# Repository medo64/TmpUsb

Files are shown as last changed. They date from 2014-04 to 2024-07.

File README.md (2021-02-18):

# TmpUsb

TmpUsb is presented to a computer as an USB disk drive 11 KB in size (7-8 KB
usable). This drive can be then used to store any data (providing that size is
not the issue) but primary idea is to use it for the encryption keys. Once all
data has been copied to it, user would perform "arming" thus enabling
self-erase after approximately 3 seconds of being unplugged.

Basic use case for such behavior would be a BitLocker key storage. Having
encrypted server brings a lot of security benefits but with a cost of
re-entering keys on every restart. BitLocker can work around that by allowing
you to store keys on USB in order to decrypt content automatically.
Unfortunately this means that, if your server is stolen, you also give your
encryption key with it thus nullifying encryption.

By using TmpUsb your encryption keys will be deleted rendering data on stolen
server completely unusable. While this won't bring your server back, at least
data won't be readable any more.

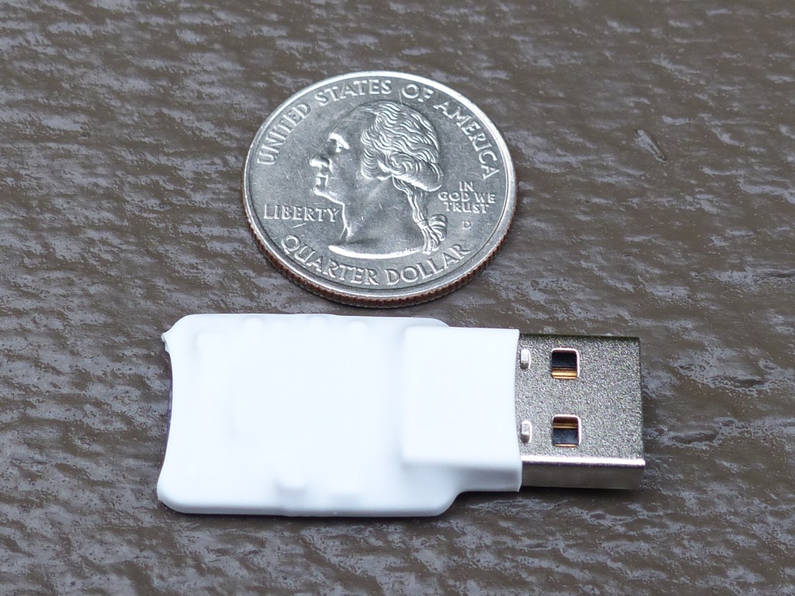
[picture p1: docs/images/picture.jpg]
TmpUsb


## How It Works

When you plug TmpUsb in for the first time, it will start in "Not Armed" mode,
as visible from drive's label. Visually you would recognize this mode by the
fact that LED is on. At that time you can freely use it as you would any
standard USB drive. At this time you would copy your encryption keys to it and
change its label to "Arm" and unplug it.

On next plug-in (might be on another computer) LED will turn off and drive will
be considered armed. In this state drive will still behave as a standard USB
drive but only while it has power. If there is a power loss longer than
approximately three seconds (configurable, to allow for computer reset) drive
will self-erase and return to an empty state.

## LED

There is a single LED on a drive. If it is on, drive hasn't been armed and it
is safe to unplug it without going into risk of losing data to self-erase. Once
drive is armed, LED will turn off.

Upon self-erase, device will quickly blink three times. If self erasure was due
to validation error (i.e. drive content was corrupted) it will blink five
times.

## Commands

All commands are entered by changing drive label. Casing is not important.

### Arm

Gives command to TmpUsb to be "armed" on next plugin. This fits scenario where
user prepares encryption keys on one computer, arms TmpUsb and then plugs it in
on another computer. Only once TmpUsb has been plugged in for a second time, it
is considered armed and any further label changes won't change that status. In
this mode TmpUsb will tolerate short power loss (approximate three seconds) but
anything longer will trigger self-erase.

### ArmMax

As with Arm command, this will cause TmpUsb to be armed on next plugin.
However, unlike with Arm command, any power failure will trigger self-erasure
regardless of power-loss duration. On most computers this means that
self-erasure will be also triggered by a simple reset.

### Armed

Immediately "arms" TmpUsb without need to wait until next plugin. This is
useful in case where preparation of encryption keys is done on same computer
where those keys are to be used. It is just a shortcut that skips need for
unplug-plug that Arm command needs. Once armed, LED will be turned off and
status will remain armed even if drive label gets further changes.

### Calibrate

If standard power-loss buffer duration (approximately three seconds) is not
satisfactory, user can change drive label to `Calibrate` and unplug the drive.
Once drive is plugged back in, it will determine duration it was plugged out
for and use that as a new default. Notice that drive will be erased and its
label will say what is raw ADC value for given time. Do try to avoid values
less than 3. Due to nature of time keeping via the capacitor, values are really
rough and they are unusable beyond 10 seconds. Value determined by this
procedure will be used until either ArmMax or Reset are given. At that time
TmpUsb will revert to default three seconds.

### Reset

On next plug-in TmpUsb will perform self-erasure together with reset of all
settings.

## Security Risks

As expected, there are some security risks involved.

Major one is connected with fact that erasure of data, due to TmpUsb having no
battery, is possible only on next plug-in. If attacker is fast enough, he can
plug TmpUsb in another computer without triggering erasure. Mitigation strategy
for this attack is using `ArmMax` command in order to trigger erasure as soon
as power is lost.

Similarly, attacker can charge capacitor without actually turning TmpUsb on. On
next plug-in TmpUsb will think that less time passed than it actually has.
Mitigation strategy is also using `ArmMax` command.

Even using `ArmMax` you are not safe if attacker is technically savvy and has
access to TmpUsb that is currently working. It can put another power source in
parallel to USB and thus TmpUsb won't be aware at any time that the power was
lost.

Internal key storage is encrypted using the security feature of microcontroller
itself. In ideal world this would mean that, even if attacker has direct access
to chip, nobody would be able to read data without running it first. Of
course, this is intended to stop normal attackers only. Somebody with unlimited
resources (e.g. NSA) will not be deterred by this.

Regardless of these attacks, TmpUsb will probably protect you from 99.9%
attackers, especially if they are not aware its presence. It is not be-all and
end-all device but it surely beats keeping keys on a normal USB drive.

## Known Issues

Device has no battery, time is kept only by monitoring voltage decay on a big
capacitor. Major downfall is the fact that such timing is imprecise and doesn't
allow for a big time spans. In practice TmpUsb can deal with up to 10 seconds
of delay.

Since most operating systems cannot really format such a small drive and such
attempt might possibly damage logical structure, decision has been made to
check MBR and boot sector (including partition table) areas on every boot.
Effect of this verification is that any change to verified areas is not
possible and drive will self-erase if such change is noted.

Chip used for TmpUsb has flash specified for at least 10000 write cycles. Since
there is no block remapping as it is custom on the modern flash drives, this
roughly means that you can safely write to this drive approximately 5000 times
(it does suffer from high write amplification). While it will probably handle a
bit more, this is definitely not the device when constant writing is expected.

Total size of this drive is 11 KB. However, this is not a size user will have
available. Six sectors (3 KB) are immediately taken by mandatory MBR and boot
sector, followed by FAT and a root directory entries. OS only gets to see 8 KB.
Once drive is plugged-in, some Windows versions will add its System Volume
Information folder on each drive it sees and that means that it gets hit with
additional 1 KB penalty and at least four directory entries are gone. Under
Windows available size is thus 7-8 KB (depending on version) while we get 8 KB
under Linux.

---

*You can check my blog and other projects at [www.medo64.com](https://www.medo64.com/).*

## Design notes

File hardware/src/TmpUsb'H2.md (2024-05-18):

## TmpUsb: USB H2 plug

| | |
|---|---|
| Size | 26.0 x 17.0 mm ~ 0.7 sqin |
| VID  | 0x04D8 |
| PID  | 0xF777 |

### Parts

|  # | Part name | RefDes  | DigiKey |
|---:|---|---|---|
|  2 | C 100nF /10V X7R (0805) | C1 C2 | 399-1167-1-ND |
|  2 | C 1uF /10V X5R (0805) | C3 C4 | 1276-6471-1-ND |
|  2 | C 10uF /10V X5R (0805) | C5 C6 | 478-5167-6-ND |
|  2 | D Schottky 30V 800mA (SOD323) | D1-D2 | CUS08F30H3FCT-ND |
|  1 | DS LED (0805) | DS1 | 475-1415-1-ND |
|  1 | L Ferrite 40Ohm (0805) | L1 | 445-2201-1-ND |
|  1 | J USB 2x5 plug, horizontal | J1 | A106395-ND |
|  1 | J AMP 292133-3 (3w) | J2 | A100945-ND |
|  2 | R 1K 0.125W (0805) | R1 R2 | RMCF0805FT1K00CT-ND |
|  1 | R 10K 0.125W (0805) | R3 | RMCF0805JT10K0CT-ND |
|  1 | R 100K 0.125W (0805) | R4 | RMCF0805JT100KCT-ND |
|  1 | U PIC18F26J50-I/SS (SSOP-28) | U1 | PIC18F26J50-I/SS-ND |
|  1 | VR MCP1700 (SOT-23) | VR1 | MCP1700T3302ETTCT-ND |

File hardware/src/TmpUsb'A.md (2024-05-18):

## TmpUsb: USB A plug

| | |
|---|---|
| Size | 26.0 x 17.0 mm ~ 0.7 sqin |
| VID  | 0x04D8 |
| PID  | 0xF777 |

### Parts

|  # | Part name | RefDes  | DigiKey | Newark  |
|---:|---|---|---|---|
|  2 | C 100nF /10V X7R (0805) | C1 C2 | 399-1167-1-ND | 68R4903 |
|  2 | C 1uF /10V X5R (0805) | C3 C4 | 1276-6471-1-ND | 97K0638 |
|  2 | C 10uF /10V X5R (0805) | C5 C6 | 478-5167-6-ND | 13T1208 |
|  1 | DS LED (0805) | DS1 | 475-1415-1-ND | 34C8663 |
|  1 | L Ferrite 40Ohm (0805) | L1 | 445-2201-1-ND | 89R3121 |
|  1 | J USB A, plug, horizontal | J1 | WM3983CT-ND | 01J8375 |
|  2 | R 1K 0.125W (0805) | R1 R2 | RMCF0805FT1K00CT-ND | 01P2109 |
|  1 | R 10K 0.125W (0805) | R3 | RMCF0805JT10K0CT-ND | 05M4535 |
|  1 | R 100K 0.125W (0805) | R4 | RMCF0805JT100KCT-ND | 68R0231 |
|  1 | U PIC18F26J50-I/SS (SSOP-28) | U1 | PIC18F26J50-I/SS-ND | 98M1806 |
|  1 | VR MCP1700 (SOT-23) | VR1 | MCP1700T3302ETTCT-ND | 88H9817 |

1/2" heat-shrink tubing, 30mm

### Suggested Soldering order

Here is the suggested order for easy hand soldering.

|  # | Part name | RefDes  |
|---:|---|---|
|  1 | U PIC18F26J50-I/SS (SSOP-28) | U1 |
|  1 | VR MCP1700 (SOT-23) | VR1 |
|  2 | C 100nF /10V X7R (0805) | C1 C2 |
|  2 | C 1uF /10V X5R (0805) | C3 C4 |
|  2 | C 10uF /10V X5R (0805) | C5 C6 |
|  1 | L Ferrite 40Ohm (0805) | L1 |
|  1 | DS LED (0805) | DS1 |
|  1 | R 10K 0.125W (0805) | R3 |
|  2 | R 1K 0.125W (0805) | R1 R2 |
|  1 | R 100K 0.125W (0805) | R4 |
|  1 | P USB A, plug, horizontal | P1 |

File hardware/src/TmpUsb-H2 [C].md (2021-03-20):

## TmpUsb: USB 2.0 motherboard header

This variant is intended for direct plug into the motherboard's 2.0 header.

| | |
|---|---|
| Size | 21.0 x 17.0 mm ~ 0.6 sqin |
| VID  | 0x04D8 |
| PID  | 0xF777 |

### Parts

|  # | Part name | RefDes  | DigiKey |
|---:|---|---|---|
|  2 | C 100nF /10V X7R (0805) | C1 C2 | 311-1142-1-ND |
|  2 | C 1uF /10V X5R (0805) | C3 C4 | 1276-6471-1-ND |
|  2 | C 10uF /10V X5R (0805) | C5 C6 | 478-5167-6-ND |
|  1 | DS LED (0805) | DS1 | 475-1415-1-ND |
|  1 | L Ferrite 40Ohm (0805) | L1 | 445-2201-1-ND |
|  1 | P USB2 Header F (2x5w) | P1 | A106395-ND † |
|  2 | R 1K 0.125W (0805) | R1 R2 | RMCF0805FT1K00CT-ND  |
|  1 | R 10K 0.125W (0805) | R3 | RMCF0805JT10K0CT-ND  |
|  1 | R 100K 0.125W (0805) | R4 | RMCF0805JT100KCT-ND  |
|  1 | U PIC18F26J50-I/SS (SSOP-28) | U1 | PIC18F26J50-I/SS-ND  |
|  1 | VR MCP1700 (SOT-23) | VR1 | MCP1700T3302ETTCT-ND |

† This connector is not an excellent match but the best I could find on
  DigiKey.

### Suggested Soldering order

Here is the suggested order for easy hand soldering.

|  # | Part name | RefDes  |
|---:|---|---|
|  1 | U PIC18F26J50-I/SS (SSOP-28) | U1 |
|  1 | VR MCP1700 (SOT-23) | VR1 |
|  2 | R 1K 0.125W (0805) | R1 R2 |
|  1 | R 10K 0.125W (0805) | R3 |
|  1 | R 100K 0.125W (0805) | R4 |
|  2 | C 10uF /10V X5R (0805) | C5 C6 |
|  2 | C 1uF /10V X5R (0805) | C3 C4 |
|  2 | C 100nF /10V X7R (0805) | C1 C2 |
|  1 | L Ferrite 40Ohm (0805) | L1 |
|  1 | DS LED (0805) | DS1 |
|  1 | P USB2 Header F (2x5w) | P1 |

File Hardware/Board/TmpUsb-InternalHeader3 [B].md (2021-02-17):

### TmpUsb ###

This variant is intended for direct plug into the motherboard's 3.0 header.

| | |
|---|---|
| Size | 24.0 x 22.0 mm ~ 0.8 sqin |
| VID  | 0x04D8 |
| PID  | 0xF777 |

#### Parts ####

|  # | Part name | RefDes  | DigiKey |
|---:|---|---|---|
|  2 | C 100nF /10V X7R (0603) | C1 C2 | 1276-1934-1-ND |
|  2 | C 1uF /10V X5R (0605) | C3 C4 | 1276-6524-1-ND |
|  2 | C 10uF /10V X5R (0805) | C5 C6 | 1276-1119-1-ND |
|  1 | DS LED (0805) | DS1 | 160-1468-1-ND |
|  1 | J USB A 3.0, receptacle, horizontal  | J1 | 609-4662-ND |
|  1 | L Ferrite 30Ohm (0603) | L1 | 490-1035-1-ND |
|  1 | P USB header, r/a plug | P1 | SQW-110-01-L-D-020 † |
|  2 | R 1K 0.1W (0603) | R1 R2 | RMCF0603FT1K00CT-ND  |
|  1 | R 10K 0.1W (0603) | R3 | RMCF0603FT10K0CT-ND  |
|  1 | R 100K 0.1W (0603) | R4 | RMCF0603FT100KCT-ND  |
|  1 | U PIC18F26J50-I/SS (SSOP-28) | U1 | PIC18F26J50-I/SS-ND  |
|  1 | VR MCP1700 (SOT-23) | VR1 | MCP1700T3302ETTCT-ND |

† This connector is not an excellent match but the best I could find on
  DigiKey. It seems that blue USB connector is only available on Chinese
  sites.

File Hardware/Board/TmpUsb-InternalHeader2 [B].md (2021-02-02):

### TmpUsb ###

This variant is intended for direct plug into the motherboard's 2.0 header.

| | |
|---|---|
| Size | 28.0 x 17.5 mm ~ 0.8 sqin |
| VID  | 0x04D8 |
| PID  | 0xF777 |

#### Parts ####

|  # | Part name | RefDes  | DigiKey | Newark  |
|---:|---|---|---|---|
|  2 | C 100nF /10V X7R (0805) | C1 C2 | 311-1142-1-ND | 68R4903 |
|  2 | C 1uF /10V X5R (0805) | C3 C4 | 1276-6471-1-ND | 97K0638 |
|  2 | C 10uF /10V X5R (0805) | C5 C6 | 478-5167-6-ND | 13T1208 |
|  1 | DS LED (0805) | DS1 | 475-1415-1-ND | 34C8663 |
|  1 | J USB A, receptable, horizontal  | J1 | ED2989-ND | 46P5302 |
|  1 | L Ferrite 40Ohm (0805) | L1 | 445-2201-1-ND | 89R3121 |
|  1 | P USB header, r/a plug | P1 | S5558-ND | 15P2884 |
|  2 | R 1K 0.125W (0805) | R1 R2 | RMCF0805FT1K00CT-ND | 01P2109 |
|  1 | R 10K 0.125W (0805) | R3 | RMCF0805JT10K0CT-ND | 05M4535 |
|  1 | R 100K 0.125W (0805) | R4 | RMCF0805JT100KCT-ND | 68R0231 |
|  1 | U PIC18F26J50-I/SS (SSOP-28) | U1 | PIC18F26J50-I/SS-ND | 98M1806 |
|  1 | VR MCP1700 (SOT-23) | VR1 | MCP1700T3302ETTCT-ND | 88H9817 |

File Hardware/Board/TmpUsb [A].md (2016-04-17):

### TmpUsb ###

| | |
|---|---|
| Size | 22.5 x 17.0 mm ~ 0.6 sqin |
| VID  | 0x04D8 |
| PID  | 0xF777 |

#### Parts ####

|  # | Part name | RefDes  | DigiKey | Newark  |
|---:|---|---|---|---|
|  2 | C 100nF /16V X7R (0805) | C1 C2 | 399-1170-1-ND | 68R4903 |
|  2 | C 1uF /16V X5R (0805) | C3 C4 | 490-1691-1-ND | 97K0638 |
|  2 | C 10uF /16V X5R (0805) | C5 C6 | 399-8013-1-ND | 13T1208 |
|  1 | DS LED (0805) | DS1 | 475-1415-1-ND | 34C8663 |
|  1 | L Ferrite 40Ohm (0805) | L1 | 445-2201-1-ND | 89R3121 |
|  1 | P USB A, plug, horizontal | P1 | WM3983CT-ND | 01J8375 |
|  2 | R 1K 0.125W (0805) | R1 R2 | RMCF0805FT1K00CT-ND | 01P2109 |
|  1 | R 10K 0.125W (0805) | R3 | RMCF0805JT10K0CT-ND | 05M4535 |
|  1 | R 100K 0.125W (0805) | R4 | RMCF0805JT100KCT-ND | 68R0231 |
|  1 | U PIC18F26J50-I/SS (SSOP-28) | U1 | PIC18F26J50-I/SS-ND | 98M1806 |
|  1 | VR MCP1700 (SOT-23) | VR1 | MCP1700T3302ETTCT-ND | 88H9817 |

1/2" heat-shrink tubing, 30mm

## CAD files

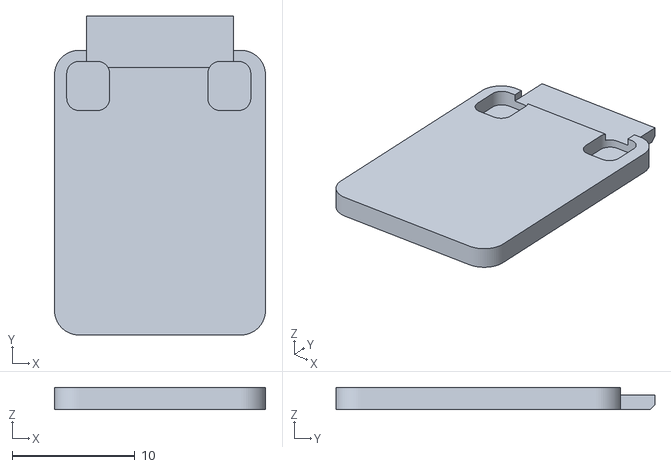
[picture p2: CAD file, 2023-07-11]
hardware/src/case/TmpUsb'A Case Bottom.stl
17.2 x 26.0 x 1.80

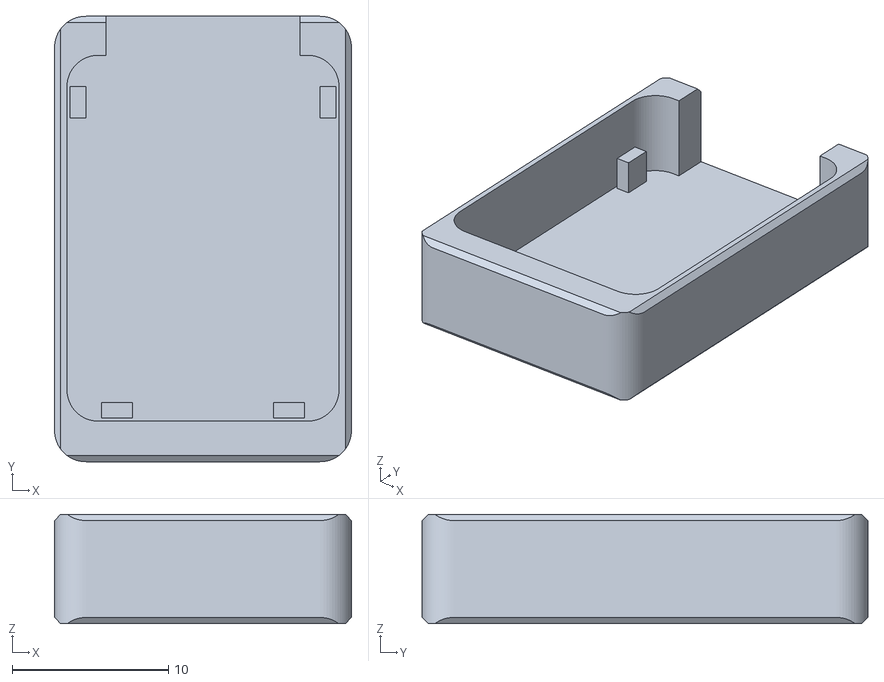
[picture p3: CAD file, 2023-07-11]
hardware/src/case/TmpUsb'A Case Top.stl
19.0 x 28.5 x 7.00

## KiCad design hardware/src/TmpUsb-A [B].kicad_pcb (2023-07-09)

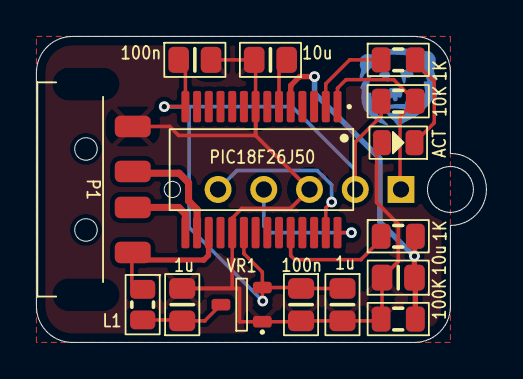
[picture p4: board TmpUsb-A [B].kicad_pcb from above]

Board: 2 copper layers, 25.0 x 17.0 mm, 16 parts (1 on the bottom side), 12 nets.

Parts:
C1, C2: 100n; C (0805)
C3, C4: 1u; C (0805)
C5, C6: 10u; C (0805)
DS1: ACT; DS (0805)
L1: 40R; L Ferrite (0805)
P1: 48037-2200; P USB 2.0 (4w)
R1, R2: 1K; R (0805)
R3: 10K; R (0805)
R4: 100K; R (0805)
U1: PIC18F26J50; U Micro PIC18F26J50 (SSOP-28)
VR1: MCP1700; VR LDO MCP1700 (SOT23-3)
Z?: Medo64; Z Icon [Medo64]

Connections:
+3.3V: C1.1, C2.1, C4.1, R3.1, U1.14, U1.20, VR1.2
+5V: C3.1, L1.2, VR1.3
CAP: C6.1, R2.2, R4.1, U1.5
CAP_POWER: R2.1, U1.24
GND: C1.2, C2.2, C3.2, C4.2, C5.2, C6.2, DS1.2, P1.4, R4.2, U1.8, U1.19, VR1.1
ICSP_VPP: R3.2, U1.1
LED: R1.1, U1.2
LED': DS1.1, R1.2
USB_D+: P1.3, U1.16
USB_D-: P1.2, U1.15
VCAP: C5.1, U1.6
VCC: L1.1, P1.1, U1.17

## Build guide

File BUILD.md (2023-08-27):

## Building TmpUsb

### Hardware

PCB was designed in [DipTrace 3.3](https://diptrace.com/) and gerber files can
be exported from the same. There are three distint versions:

* [USB A plug](hardware/src/TmpUsb'A.md)
* [USB 2.0 motherboard header](hardware/src/TmpUsb-H2%20%5BC%5D.md)
* [USB 3.0 motherboard header](hardware/src/TmpUsb-H3%20%5BB%5D.md)

Parts needed are similar for all three but USB 3.0 header version does use 0603
components while other two boards use 0805.

Alternatively, you can grab the latest release on GitHub and send gerbers over
to [OSH Park](http://oshpark.com/) (or any other PCB manufacturer of your
choice).

### Firmware

To build the firmware you will need the following:

* [MPLAB X IDE v5.45](https://www.microchip.com/en-us/development-tools-tools-and-software/mplab-x-ide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)
* [MPLAB XC8 Compiler v1.45](https://www.microchip.com/development-tools/pic-and-dspic-downloads-archive)

While newer versions of MPLAB X IDE will work just fine, make sure you use XC8
v1.45 to compile the firmware as it's not compatible with newer versions.

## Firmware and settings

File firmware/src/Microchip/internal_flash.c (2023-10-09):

/******************************************************************************
 
                Microchip Memory Disk Drive File System
 
 *****************************************************************************
  FileName:        Internal Flash.c
  Dependencies:    See includes section.
  Processor:       PIC18/PIC24/dsPIC33 microcontrollers
  Compiler:        Microchip XC8, XC16
  Company:         Microchip Technology, Inc.
 
  Software License Agreement
 
  The software supplied herewith by Microchip Technology Incorporated
  (the "Company") for its PIC(R) Microcontroller is intended and
  supplied to you, the Company's customer, for use solely and
  exclusively on Microchip PIC Microcontroller products. The
  software is owned by the Company and/or its supplier, and is
  protected under applicable copyright laws. All rights are reserved.
  Any use in violation of the foregoing restrictions may subject the
  user to criminal sanctions under applicable laws, as well as to
  civil liability for the breach of the terms and conditions of this
  license.
 
  THIS SOFTWARE IS PROVIDED IN AN "AS IS" CONDITION. NO WARRANTIES,
  WHETHER EXPRESS, IMPLIED OR STATUTORY, INCLUDING, BUT NOT LIMITED
  TO, IMPLIED WARRANTIES OF MERCHANTABILITY AND FITNESS FOR A
  PARTICULAR PURPOSE APPLY TO THIS SOFTWARE. THE COMPANY SHALL NOT,
  IN ANY CIRCUMSTANCES, BE LIABLE FOR SPECIAL, INCIDENTAL OR
  CONSEQUENTIAL DAMAGES, FOR ANY REASON WHATSOEVER.
********************************************************************/
//DOM-IGNORE-END

#include "string.h"
#include <fileio_config.h>
#include <fileio.h>
#include <internal_flash.h>

#include <stdint.h>
#include <stdbool.h>

#include "../io.h"


/******************************************************************************
 * Global Variables
 *****************************************************************************/

static FILEIO_MEDIA_INFORMATION mediaInformation;

/******************************************************************************
 * Prototypes
 *****************************************************************************/
void EraseBlock(const uint8_t* dest);
void WriteRow(void);
void WriteByte(unsigned char);
FILEIO_MEDIA_INFORMATION * MediaInitialize(void);
void UnlockAndActivate(uint8_t);

//Arbitrary, but "uncommon" value.  Used by UnlockAndActivateWR() to enhance robustness.
#define NVM_UNLOCK_KEY  (uint8_t)0xB5

/******************************************************************************
 * Function:        uint8_t MediaDetect(void* config)
 *
 * PreCondition:    InitIO() function has been executed.
 *
 * Input:           void
 *
 * Output:          true   - Card detected
 *                  false   - No card detected
 *
 * Side Effects:    None
 *
 * Overview:        None
 *
 * Note:            None
 *****************************************************************************/
uint8_t FILEIO_InternalFlash_MediaDetect(void* config)
{
    return true;
}//end MediaDetect

/******************************************************************************
 * Function:        uint16_t SectorSizeRead(void)
 *
 * PreCondition:    MediaInitialize() is complete
 *
 * Input:           void
 *
 * Output:          uint16_t - size of the sectors for this physical media.
 *
 * Side Effects:    None
 *
 * Overview:        None
 *
 * Note:            None
 *****************************************************************************/
uint16_t FILEIO_InternalFlash_SectorSizeRead(void* config)
{
    return FILEIO_CONFIG_MEDIA_SECTOR_SIZE;
}

/******************************************************************************
 * Function:        uint32_t ReadCapacity(void)
 *
 * PreCondition:    MediaInitialize() is complete
 *
 * Input:           void
 *
 * Output:          uint32_t - size of the "disk" - 1 (in terms of sector count).
 *                  Ex: In other words, this function returns the last valid 
 *                  LBA address that may be read/written to.
 *
 * Side Effects:    None
 *
 * Overview:        None
 *
 * Note:            None
 *****************************************************************************/
uint32_t FILEIO_InternalFlash_CapacityRead(void* config)
{
    //The SCSI READ_CAPACITY command wants to know the last valid LBA address 
    //that the host is allowed to read or write to.  Since LBA addresses start
    //at and include 0, a return value of 0 from this function would mean the 
    //host is allowed to read and write the LBA == 0x00000000, which would be 
    //1 sector worth of capacity.
    //Therefore, the last valid LBA that the host may access is 
    //DRV_FILEIO_INTERNAL_FLASH_TOTAL_DISK_SIZE - 1.
        
    return ((uint32_t)DRV_FILEIO_INTERNAL_FLASH_TOTAL_DISK_SIZE - 1);
}

/******************************************************************************
 * Function:        uint8_t InitIO(void)
 *
 * PreCondition:    None
 *
 * Input:           void
 *
 * Output:          true   - Card initialized
 *                  false   - Card not initialized
 *
 * Side Effects:    None
 *
 * Overview:        None
 *
 * Note:            None
 *****************************************************************************/
uint8_t FILEIO_InternalFlash_InitIO (void* config)
{
    return  true;
}

/******************************************************************************
 * Function:        uint8_t MediaInitialize(void)
 *
 * PreCondition:    None
 *
 * Input:           None
 *
 * Output:          Returns a pointer to a MEDIA_INFORMATION structure
 *
 * Overview:        MediaInitialize initializes the media card and supporting variables.
 *
 * Note:            None
 *****************************************************************************/
FILEIO_MEDIA_INFORMATION * FILEIO_InternalFlash_MediaInitialize(void* config)
{
    mediaInformation.validityFlags.bits.sectorSize = true;
    mediaInformation.sectorSize = FILEIO_CONFIG_MEDIA_SECTOR_SIZE;
    
    mediaInformation.errorCode = MEDIA_NO_ERROR;
    return &mediaInformation;
}//end MediaInitialize
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

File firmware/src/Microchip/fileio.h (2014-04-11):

/******************************************************************************
*
*                        Microchip File I/O Library
*
******************************************************************************
* FileName:           fileio.h
* Dependencies:       system_config.h, system.h
* Processor:          PIC24/dsPIC30/dsPIC33
* Compiler:           XC16
* Company:            Microchip Technology, Inc.
*
* Software License Agreement
*
* The software supplied herewith by Microchip Technology Incorporated
* (the "Company") for its PICmicro(R) Microcontroller is intended and
* supplied to you, the Company's customer, for use solely and
* exclusively on Microchip PICmicro Microcontroller products. The
* software is owned by the Company and/or its supplier, and is
* protected under applicable copyright laws. All rights are reserved.
* Any use in violation of the foregoing restrictions may subject the
* user to criminal sanctions under applicable laws, as well as to
* civil liability for the breach of the terms and conditions of this
* license.
*
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
********************************************************************/


#ifndef  _FILEIO_DOT_H
#define  _FILEIO_DOT_H

#include <stdint.h>
#include <stdbool.h>
#include <stddef.h>
#include "system_config.h"
#include "system.h"

#if __XC16_VERSION__ == 1020
#error XC16 v1.20 is not compatible with this firmware, please use a later version of the XC16 compiler.
#endif

#if __XC8_VERSION == 1300
#error XC8 v1.30 is not compatible with this firmware, please use either XC8 v1.21 or a later version of the XC8 compiler.
#endif

/*******************************************************************/
/*                     Structures and defines                     */
/*******************************************************************/

// Enumeration for general purpose return values
typedef enum
{
    FILEIO_RESULT_SUCCESS = 0,                  // File operation was a success
    FILEIO_RESULT_FAILURE = -1                  // File operation failed
} FILEIO_RESULT;

// Definition to indicate an invalid file handle
#define FILEIO_INVALID_HANDLE       NULL

#define FILEIO_FILE_NAME_LENGTH_8P3                 12          // Maximum file name length for 8.3 formatted files
#define FILEIO_FILE_NAME_LENGTH_8P3_NO_RADIX        11          // Maximum file name length for 8.3 formatted files with no radix

// Enumeration for formatting modes
typedef enum
{
    FILEIO_FORMAT_ERASE = 0,            // Erases the contents of the partition
    FILEIO_FORMAT_BOOT_SECTOR           // Creates a boot sector based on user-specified information and erases any existing information
} FILEIO_FORMAT_MODE;

// Enumeration for specific return codes
typedef enum
{
    FILEIO_ERROR_NONE = 0,                      // No error
    FILEIO_ERROR_ERASE_FAIL,                    // An erase failed
    FILEIO_ERROR_NOT_PRESENT,                   // No device was present
    FILEIO_ERROR_NOT_FORMATTED,                 // The disk is of an unsupported format
    FILEIO_ERROR_BAD_PARTITION,                 // The boot record is bad
    FILEIO_ERROR_UNSUPPORTED_FS,                // The file system type is unsupported
    FILEIO_ERROR_INIT_ERROR,                    // An initialization error has occured
    FILEIO_ERROR_UNINITIALIZED,                 // An operation was performed on an uninitialized device
    FILEIO_ERROR_BAD_SECTOR_READ,               // A bad read of a sector occured
    FILEIO_ERROR_WRITE,                         // Could not write to a sector
    FILEIO_ERROR_INVALID_CLUSTER,               // Invalid cluster value > maxcls
    FILEIO_ERROR_DRIVE_NOT_FOUND,               // The specified drive could not be found
    FILEIO_ERROR_FILE_NOT_FOUND,                // Could not find the file on the device
    FILEIO_ERROR_DIR_NOT_FOUND,                 // Could not find the directory
    FILEIO_ERROR_BAD_FILE,                      // File is corrupted
    FILEIO_ERROR_DONE,                          // No more files in this directory
    FILEIO_ERROR_COULD_NOT_GET_CLUSTER,         // Could not load/allocate next cluster in file
    FILEIO_ERROR_FILENAME_TOO_LONG,             // A specified file name is too long to use
    FILEIO_ERROR_FILENAME_EXISTS,               // A specified filename already exists on the device
    FILEIO_ERROR_INVALID_FILENAME,              // Invalid file name
    FILEIO_ERROR_DELETE_DIR,                    // The user tried to delete a directory with FILEIO_Remove
    FILEIO_ERROR_DELETE_FILE,                   // The user tried to delete a file with FILEIO_DirectoryRemove
    FILEIO_ERROR_DIR_FULL,                      // All root dir entry are taken
    FILEIO_ERROR_DRIVE_FULL,                     // All clusters in partition are taken
    FILEIO_ERROR_DIR_NOT_EMPTY,                 // This directory is not empty yet, remove files before deleting
    FILEIO_ERROR_UNSUPPORTED_SIZE,              // The disk is too big to format as FAT16
    FILEIO_ERROR_WRITE_PROTECTED,               // Card is write protected
    FILEIO_ERROR_FILE_UNOPENED,                 // File not opened for the write
    FILEIO_ERROR_SEEK_ERROR,                    // File location could not be changed successfully
    FILEIO_ERROR_BAD_CACHE_READ,                // Bad cache read
    FILEIO_ERROR_FAT32_UNSUPPORTED,             // FAT 32 - card not supported
    FILEIO_ERROR_READ_ONLY,                     // The file is read-only
    FILEIO_ERROR_WRITE_ONLY,                    // The file is write-only
    FILEIO_ERROR_INVALID_ARGUMENT,              // Invalid argument
    FILEIO_ERROR_TOO_MANY_FILES_OPEN,           // Too many files are already open
    FILEIO_ERROR_TOO_MANY_DRIVES_OPEN,          // Too many drives are already open
    FILEIO_ERROR_UNSUPPORTED_SECTOR_SIZE,       // Unsupported sector size
    FILEIO_ERROR_NO_LONG_FILE_NAME,             // Long file name was not found
    FILEIO_ERROR_EOF                            // End of file reached
} FILEIO_ERROR_TYPE;
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

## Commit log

2013-08-12 Added MCLR circuit.
2013-09-16 Added battery.
2013-11-20 Added additional decoupling capacitor.
2013-11-26 Added CR2032 battery and a major refactoring.
2014-03-30 Just a standard LED.
2014-04-05 Refactoring and adding calibration label.
2014-04-05 Charging resistor is 1K.
2014-04-06 Added 100K bleed-off resistor (to get more consistent values).
2014-04-06 Adding Reset and Arm commands + some refactoring.
    [config.c]
2014-04-08 Refactoring LED position.
2014-04-09 Increasing startup charge.
2014-04-09 Fixing LED name.
2014-04-09 Erasing drive if 5V goes missing.
2014-04-14 Added USB power test points.
2014-04-30 Changing capacitor type.
2014-05-05 Heat-shrink length is adjusted.
2014-05-06 Added LED blink on write.
2014-05-06 Removing LED on/off.
2014-05-06 ArmMax reset will restore timing charge.
2014-05-12 ReadOnly arms device on next restart.
2014-10-31 Added VID/PID.
2015-09-04 Added lanyard hole.
2015-09-22 Bigger chain hole.
2015-10-05 Keychain hole is a bit bigger.
2015-10-30 Expanded ring hole.
2016-04-17 Removed lanyard hole.
2016-05-07 Re-added lanyard hole.
2021-02-02 Updated USB header connector
2021-02-03 Refactoring wires a bit
2021-02-20 Refactored to make smaller board with USB on side
2021-02-20 Refactoring silkscreen and copper pours
2021-02-21 Making 2.0 header smaller by removing USB connector
2021-02-22 Fixed USB 3.0 header connector pinout
2021-02-23 H2 has edge connector now
2021-02-23 H2 board is smaller a bit
2021-02-23 Updating USB3 motherboard header connector
2021-02-24 Fixed USB3 header connector orientation
2021-03-08 Refactoring traces a bit
2021-03-20 Added suggested soldering order
2021-03-22 Refactored to use vertical connector
2021-03-24 Added trace colors
2021-03-26 Refactoring USB traces to improve impedance
2021-03-26 Cleaning up silkscreen
2022-03-19 Removed solder mask from 5Vstby line
2023-07-09 Added KiCad PCB
    [TmpUsb [B].kicad_pcb]
2023-07-09 Fixed USB connector DRC checks
    [TmpUsb [B].kicad_pcb]
2023-07-09 Cleaning up traces and adding copper pour
    [TmpUsb [B].kicad_pcb]
2023-07-09 Renamed project files and some minor updates
    [TmpUsb-A [B].kicad_pcb]
2023-07-09 Added make script for gerber output
2023-07-09 Replaced ferrite bead footprint
    [TmpUsb-A [B].kicad_pcb]
2023-07-09 Updated footprint a bit
    [TmpUsb-A [B].kicad_pcb]
2023-07-09 Added schematics
    [TmpUsb-A [B].kicad_pcb, TmpUsb-A [B].kicad_sch]
2023-07-09 Renamed project a bit
    [TmpUsb [B].kicad_pcb, TmpUsb [B].kicad_sch]
2023-07-10 Updated make script to adjust text on PCB
2023-07-10 Updating footprints and net names
    [TmpUsb [B].kicad_pcb]
2023-07-11 Moved diode to center
    [TmpUsb [B].kicad_pcb]
2023-07-11 Pogo ICSP has copper exposed only on one side
    [TmpUsb [B].kicad_pcb]
2023-07-11 Added case models
    [TmpUsb [B] Case Bottom.stl, TmpUsb [B] Case Top.stl]
2023-07-19 Updated ferrite silkscreen
    [TmpUsb [B].kicad_pcb]
2023-07-21 Moving PIC silk-screen
    [TmpUsb [B].kicad_pcb]
2023-08-27 Cleaning up the board and updated footprints
    [TmpUsb [B].kicad_pcb, TmpUsb-A Case Bottom.stl, TmpUsb-A Case Top.stl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]
2023-08-27 Updated ICSP footprint
    [TmpUsb-A.kicad_pcb]
2023-08-27 Updated kicad PCB name
    [TmpUsb'A Case Bottom.stl, TmpUsb'A Case Top.stl, TmpUsb'A.kicad_pcb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]
2023-08-29 Using 5-pin ICSP pogo connector
    [TmpUsb'A.kicad_pcb]
2023-08-29 Updated via size
    [TmpUsb'A.kicad_pcb]
2023-08-30 Updated pogo footprint
    [TmpUsb'A.kicad_pcb]
2023-09-03 Updated silkscreen sizes
    [TmpUsb'A.kicad_pcb]
2023-09-03 Updated footprints a bit
    [TmpUsb'A.kicad_pcb]
2023-09-04 Updated footprints
    [TmpUsb'A.kicad_pcb]
2023-10-09 Rotated LED around and minor component updates
    [TmpUsb'A.kicad_pcb]
2023-10-09 Moving silkscreen around
    [TmpUsb'A.kicad_pcb]
2023-10-09 Reorganizing traces a bit
    [TmpUsb'A.kicad_pcb]
2023-10-09 First go at MB header USB
    [TmpUsb'H2.kicad_pcb]
2023-10-25 Updated pogo connector
    [TmpUsb'A.kicad_pcb]
2024-05-18 Updating footprints
    [TmpUsb'A.kicad_pcb, TmpUsb'A.kicad_sch, TmpUsb'H2.kicad_pcb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]
2024-05-18 Updated WOL connectort to AMP CT
    [TmpUsb'H2.kicad_pcb]
2024-05-18 Fixing connector designators
    [TmpUsb'A.kicad_pcb]
2024-05-18 Added case for H2 variant
    [TmpUsb'H2 Case Bottom.stl, TmpUsb'H2 Case Top.stl, TmpUsb'H2.kicad_pcb]
2024-05-19 Adjusting silkscreen a bit
    [TmpUsb'A.kicad_pcb, TmpUsb'H2.kicad_pcb]
2024-05-19 Renamed V+ nets
    [TmpUsb'A.kicad_pcb, TmpUsb'H2.kicad_pcb]
2024-05-19 Swapping diodes around
    [TmpUsb'H2.kicad_pcb]
2024-07-28 Adjusted silkscreen
    [TmpUsb'H2.kicad_pcb]
2024-07-28 Updated H2 case
    [TmpUsb'H2 Case Bottom.stl, TmpUsb'H2 Case Top.stl]
2024-07-28 Moved case to a separate directory
    [TmpUsb'A Case Bottom.stl, TmpUsb'A Case Top.stl]
